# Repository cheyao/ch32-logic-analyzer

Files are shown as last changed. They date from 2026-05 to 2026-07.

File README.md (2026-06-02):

# 200Msps 16ch logic analyzer + 20Msps oscilloscope

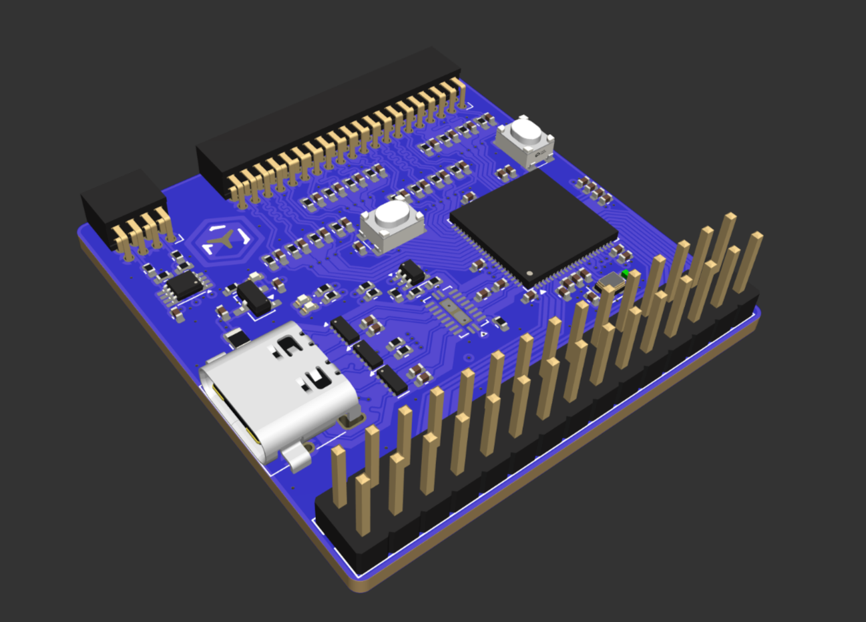
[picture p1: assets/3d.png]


This is a cheap 200Msps logic analyzer with a 20Msps analog component. It uses USB 3.2 to send data to the computer, and can also act as a ch32h417 development board.

It is usable with pulseview delivering a beautiful interface and allowing you to view all kinds of diffrent protocols. And with voltage changing, it supports 1.2V, 3.3V and 5V opration modes.

The analog channels support 20Msps at 10bit accuracy, or 5MHz at 12bit accuracy. Input range is from 0V to 5V, and it supports external triggering too!

The bottom row of header breaks out GPIO pins of various protocols, allowing the board to also become a devboard that can be programed via USB.

---

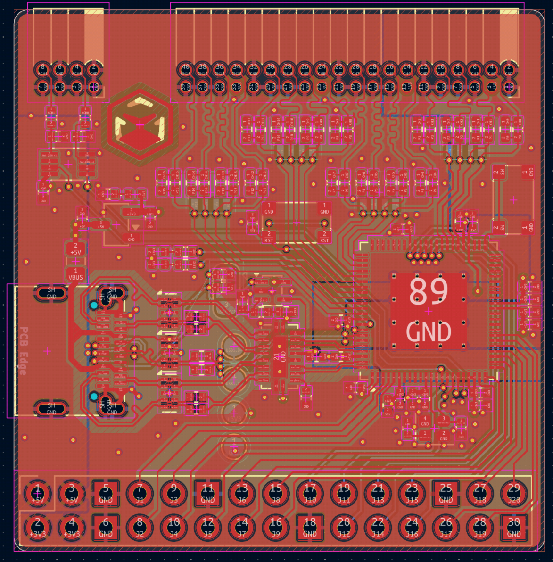
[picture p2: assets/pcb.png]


The PCB is a 4-layered board in order to preserve signal intergity on the USB 3.2 data lines. With high-quality TI active components to preserve signal quality.

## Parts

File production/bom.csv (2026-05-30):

Designator | Footprint | Quantity | Value | LCSC Part #
C1, C2 | 0402 | 2 | 33pF | C5137486
C10, C11, C12, C13, C14, C15, C16, C17, C18, C19, C20, C5, C6, C7, C8, C9 | 0402 | 16 | 15pF | C1548
C21, C22, C23, C24, C25, C26, C27, C30, C31, C32, C34, C35, C358, C359, C36, C360, C361, C38, C4 | 0402 | 19 | 100nF | C110251
C28, C29, C3, C33, C37, C39, C40 | 0402 | 7 | 4.7uF | C7472956
D1, D2, D3 | 0402 | 3 | LED | C20613596
F2 | 0805 | 1 | 1A@12V | C46640991
J1 | USB_C_Receptacle_SHOU-HAN_24P-QT | 1 | USB_C_Receptacle | C2681555
J2 | PinSocket_2x20_P1.27mm_Horizontal | 1 | Conn_02x20 | C2881906
J3 | PinSocket_2x04_P1.27mm_Horizontal | 1 | Conn_02x04 | C2881890
J4 | PinSocket_2x15_P2.54mm_Vertical | 1 | Conn_02x15 | C56496
R1, R10, R11, R12, R13, R14, R15, R16, R2, R23, R24, R25, R3, R4, R5, R6, R7, R8, R9 | 0402 | 19 | 1k | C2906864
R17, R20 | 0402 | 2 | 220R | C25091
R18, R19 | 0402 | 2 | 100R | C2906860
R21, R22 | 0402 | 2 | 5.1k | C2906874
R97, R98 | 0402 | 2 | 2.2R | C53454336
RN1, RN2, RN3, RN4 | R_Array_Convex_4x0603 | 4 | 100k | C110374
SW1, SW2 | SW_Push_SPST_TSA016 | 2 | SW_Push | C2888427
U1 | QFN-88-1EP_10x10mm_P0.4mm_EP5.7x5.7mm_ThermalVias | 1 | CH32H417MxUx
U16, U22, U23 | USON-10_2.5x1.0mm_P0.5mm | 3 | TPD4EUSB30 | C558427
U2 | VSSOP-8_2.3x2mm_P0.5mm | 1 | Opamp_Dual | C2058180
U3 | QFN-16-1EP_3x3mm_P0.5mm_EP1.75x1.75mm_ThermalVias | 1 | CH9441P | C54300797
U4 | SOT-23-3 | 1 | XC6206PxxxMR | C347376
Y1 | Crystal_SMD_2016-4Pin_2.0x1.6mm | 1 | 25MHz 20pF | C252274

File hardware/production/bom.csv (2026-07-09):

Designator | Footprint | Quantity | Value | LCSC Part #
C1, C2 | 0402 | 2 | 33pF | C5137486
C10, C11, C12, C13, C14, C15, C16, C17, C18, C19, C20, C5, C6, C7, C8, C9 | 0402 | 16 | 15pF | C1548
C21, C23, C24, C25, C26, C27, C30, C31, C32, C34, C35, C358, C359, C36, C360, C361, C38, C4 | 0402 | 18 | 100nF | C60474
C28, C29, C33, C37, C39, C40, C41 | 0402 | 7 | 4.7uF | C380302
D1, D2, D3 | 0402 | 3 | LED | C51933306
F2 | 0805 | 1 | 1A@12V | C46640991
J1 | USB_C_Receptacle_SHOU-HAN_24P-QT | 1 | USB_C_Receptacle | C2681555
J2 | PinHeader_2x20_P1.27mm_Horizontal | 1 | Conn_02x20 | C2881906
J3 | PinHeader_2x04_P1.27mm_Horizontal | 1 | Conn_02x04 | C2881890
J4, J5 | PinHeader_2x15_P2.54mm_Vertical | 2 | Conn_02x15 | C56496
R1, R10, R11, R12, R13, R14, R15, R16, R2, R23, R24, R25, R29, R3, R4, R5, R6, R7, R8, R9 | 0402 | 20 | 1k | C106235
R18, R19, R20, R30 | 0402 | 4 | 100R | C106232
R21, R22, R26, R27, R28 | 0402 | 5 | 5.1k | C105872
R97, R98 | 0402 | 2 | 2.2R | C54920775
RN1, RN2, RN3, RN4 | R_Array_Convex_4x0603 | 4 | 100k | C110374
SW1, SW2 | SW_Push_SPST_TSA016 | 2 | SW_Push | C2888427
U1 | QFN-88-1EP_10x10mm_P0.4mm_EP5.7x5.7mm_ThermalVias | 1 | CH32H417MxUx | C54973456
U16, U22, U23 | USON-10_2.5x1.0mm_P0.5mm | 3 | TPD4EUSB30 | C558427
U2 | SOT-89-3 | 1 | AMS1117-3.3 | C347256
U3 | SOT-353_SC-70-5 | 1 | LMV321 | C3029047
U5 | DHVQFN-20-1EP_2.5x4.5mm_P0.5mm_EP1x3mm | 1 | TMUXHS4212 | C2869871
Y1 | Crystal_SMD_2016-4Pin_2.0x1.6mm | 1 | 25MHz 20pF | C37635326

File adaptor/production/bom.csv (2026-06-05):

Designator | Footprint | Quantity | Value | LCSC Part #
J1 | Edge_1.27mm_02x04 | 1 | Conn_02x04_Odd_Even
J2 | Edge_1.27mm_02x20 | 1 | Conn_02x20 | C2881906
J3 | Edge_2.54mm_02x20 | 1 | Conn_02x20 | C2881906
J4 | Edge_2.54mm_02x04 | 1 | Conn_02x04_Odd_Even

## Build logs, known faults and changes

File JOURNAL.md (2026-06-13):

Day 1 - 1.5h

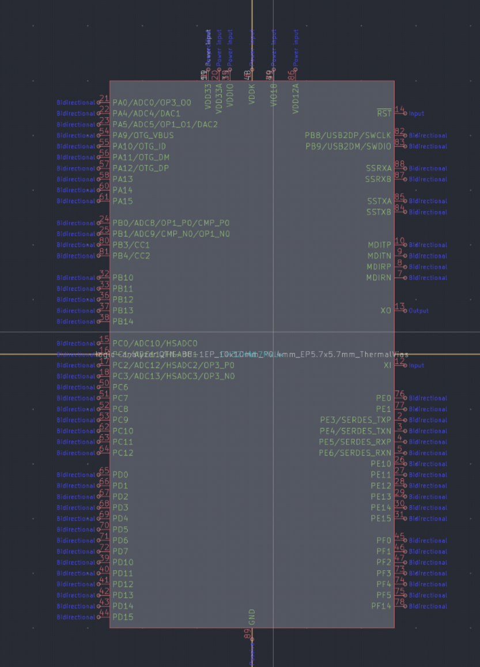
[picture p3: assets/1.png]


Drew the CH32H417 symbol and its QFN-88 footprint

---

Day 2 - 4.3h

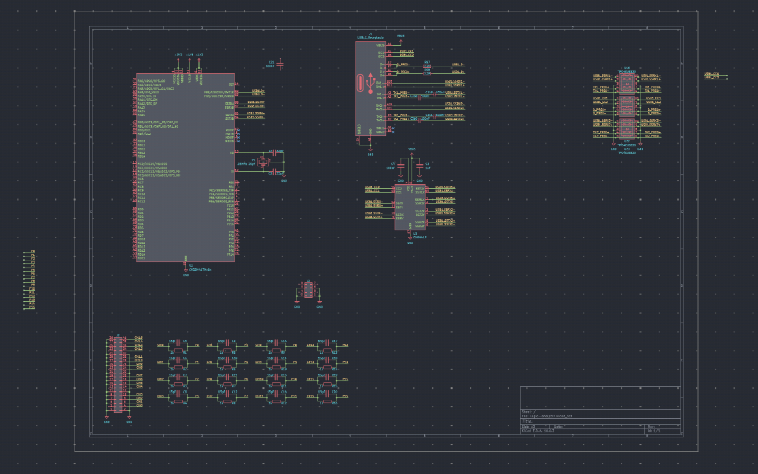
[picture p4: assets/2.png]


Improved the schmatic, picked some chips

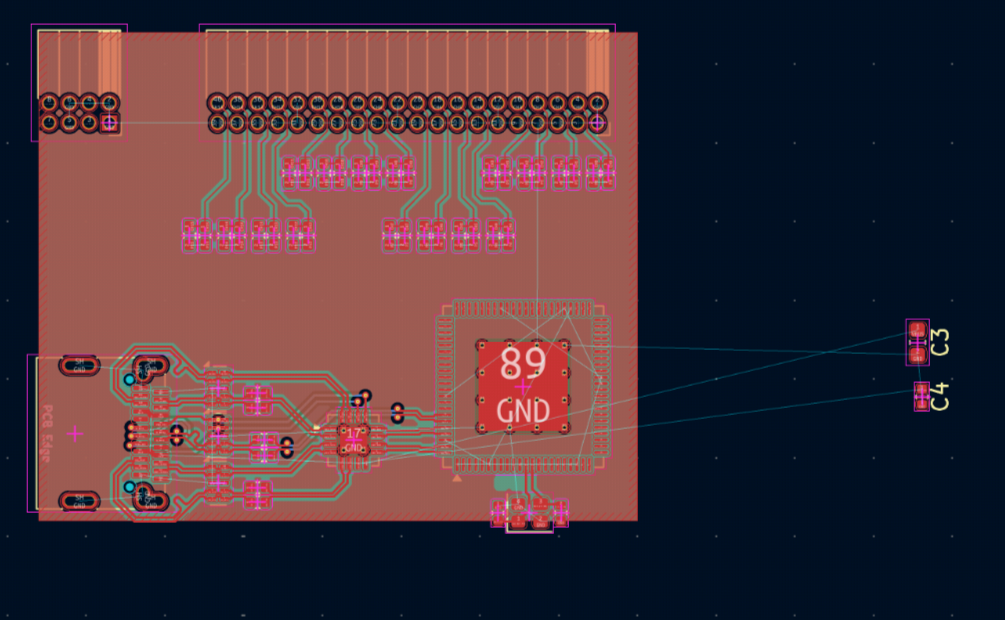
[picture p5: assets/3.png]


And started laying the board out

---

Day 3 - 6.8h

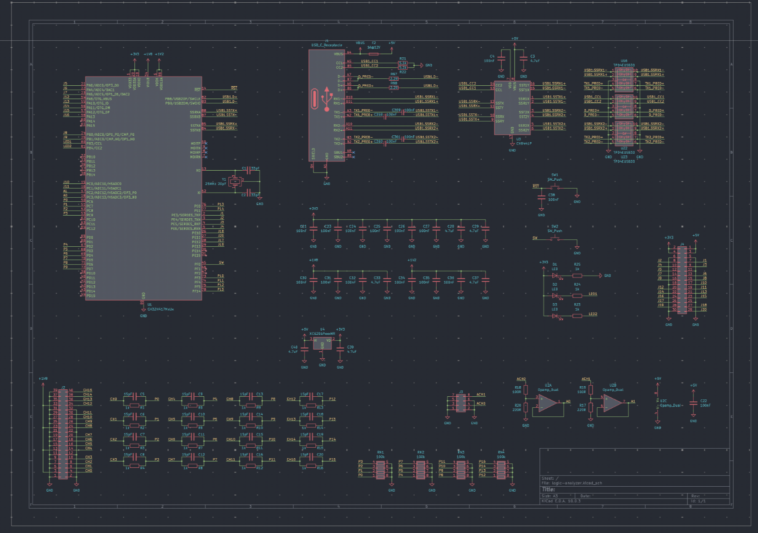
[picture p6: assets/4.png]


Finished the schematic! Added a ADC opamp voltage conv, power circuits and decoupling n more

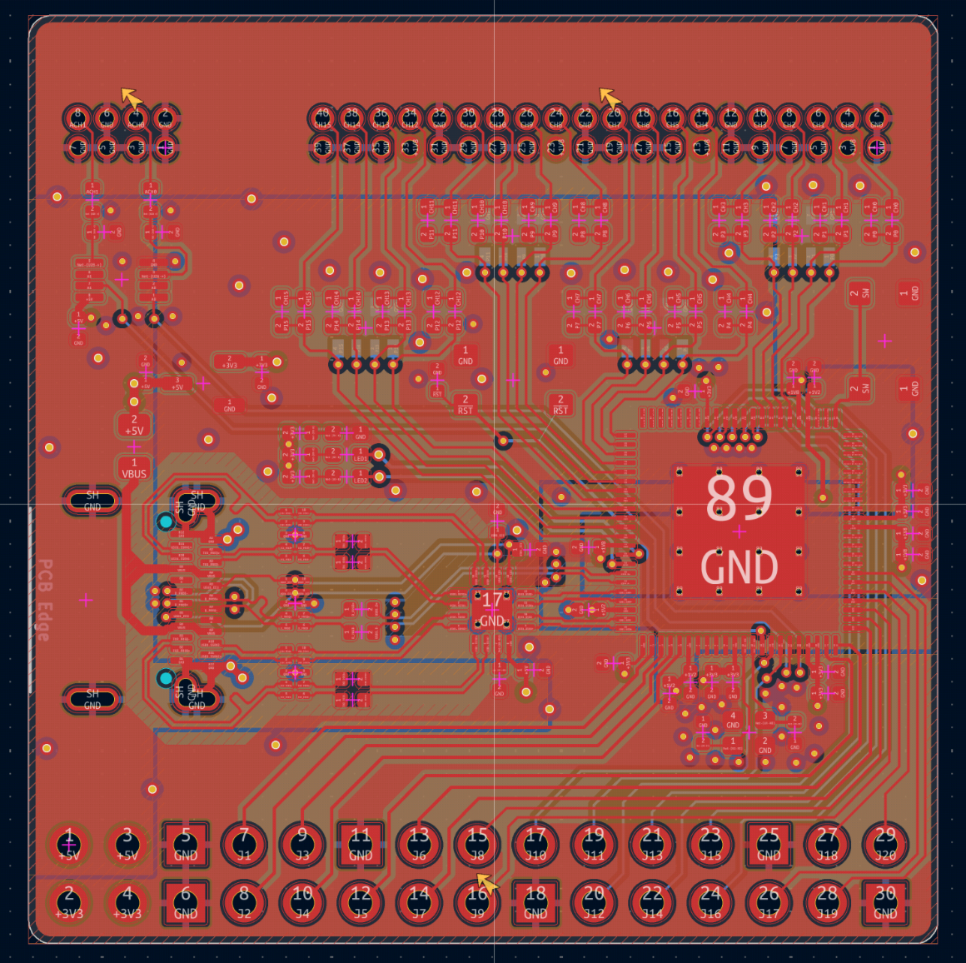
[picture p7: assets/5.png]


Then routed out the PCB, took into acount the super-high-speed routes etc

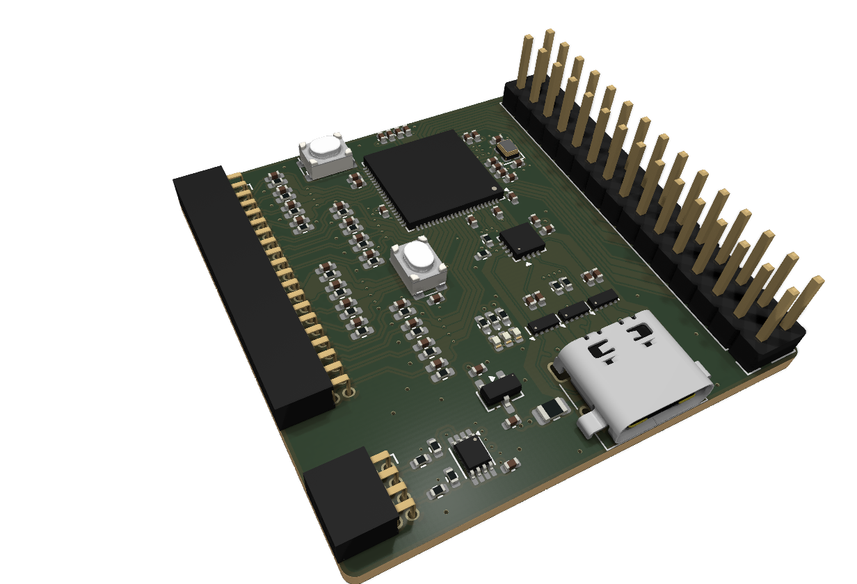
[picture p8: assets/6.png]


Also spent a bit of time fixing all the 3d models

---

Day 4 - 4.3h

Changed the unavailable parts to something more common, and used a opamp to trigger the switch instead of mcu firmware. Studied this circuit a tiny bit.

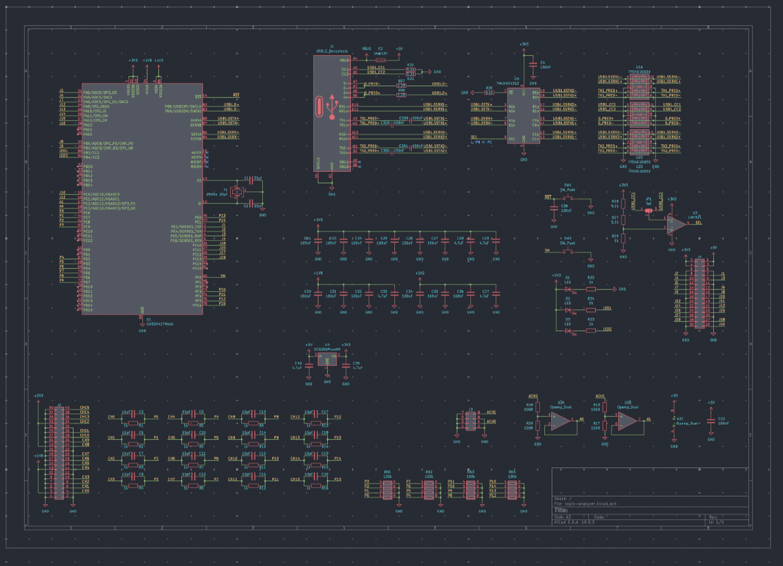
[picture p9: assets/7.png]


Also re-did the high speed routing:

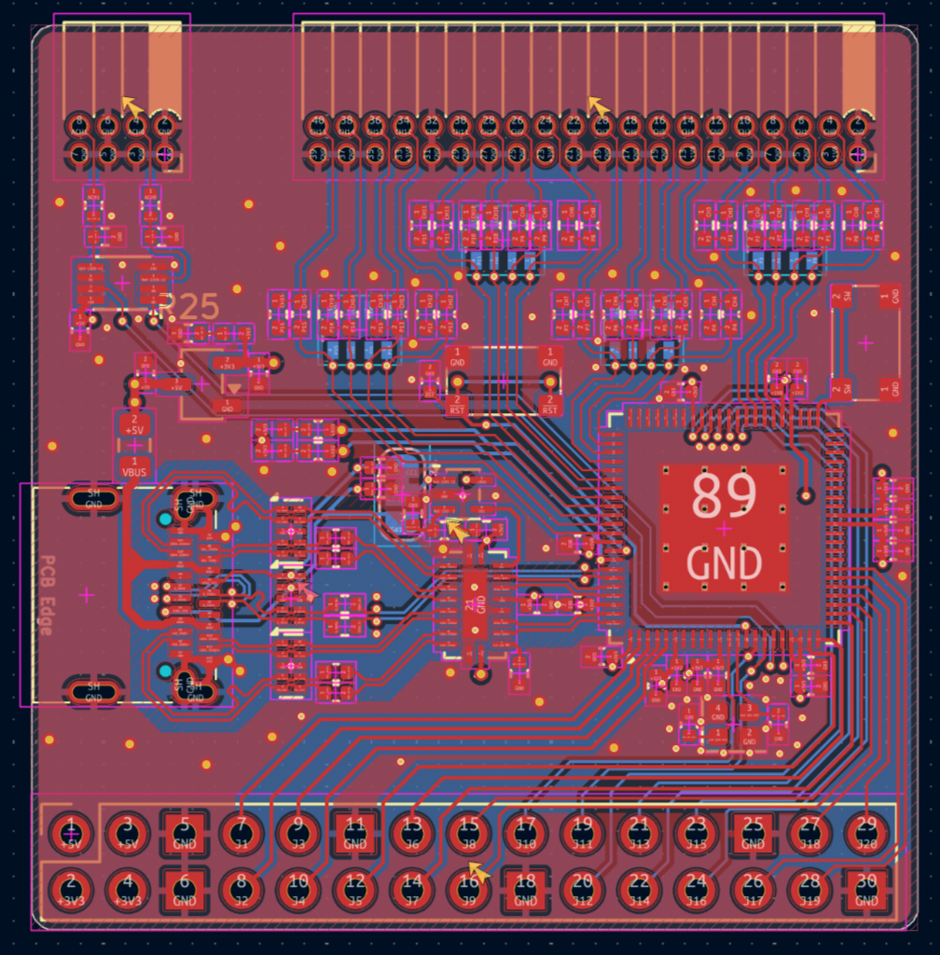
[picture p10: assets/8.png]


---

Day 5 - 1.2h

Shipped the project!

Polished everything and wrote the readme, you can see the difference between the pic above and the pic in the readme



:D

---

Day 6 - 4.6h

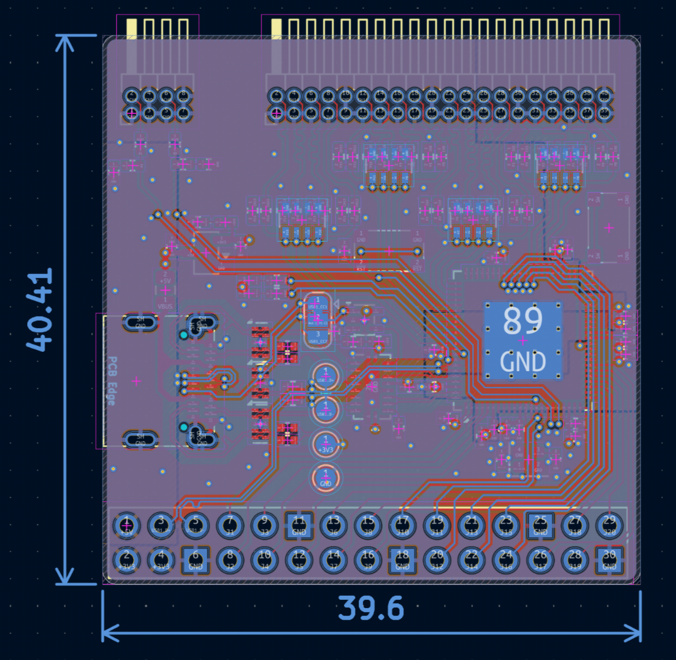
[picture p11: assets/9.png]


This time I thought about how to program the board lmao, broke out the swio pads.

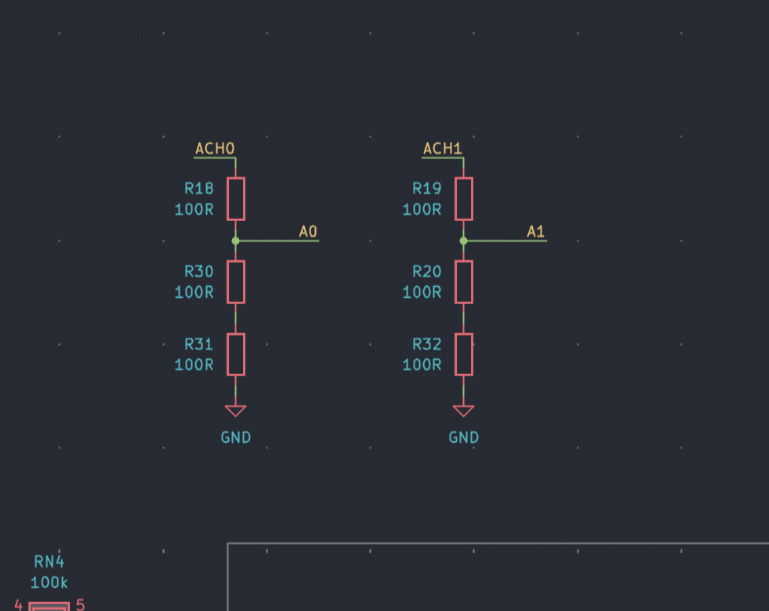
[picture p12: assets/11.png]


Also changed the OPA to resistor devider to bom opt, and changed a lot of component numbers.

Fixed the power planes, or more like optimized them

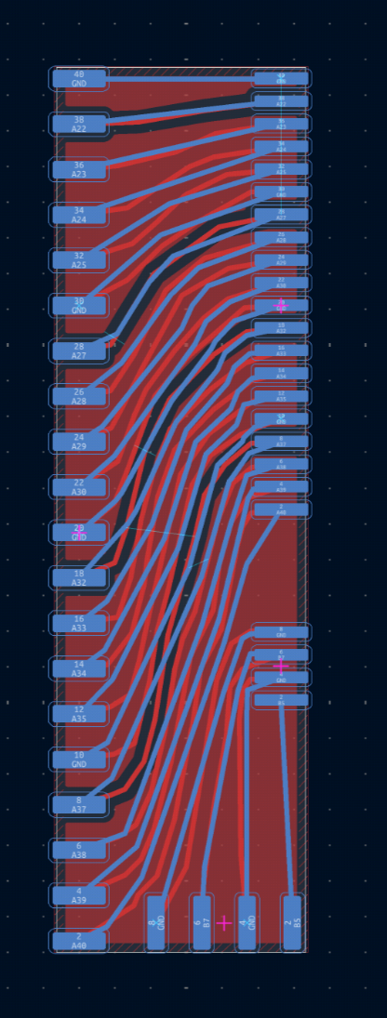
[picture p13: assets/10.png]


At the same time, I made a small breakout board to get bigger headers.

Gotten a few quotes too! Been a pita to add everything

---

Day 7 - 4.9h

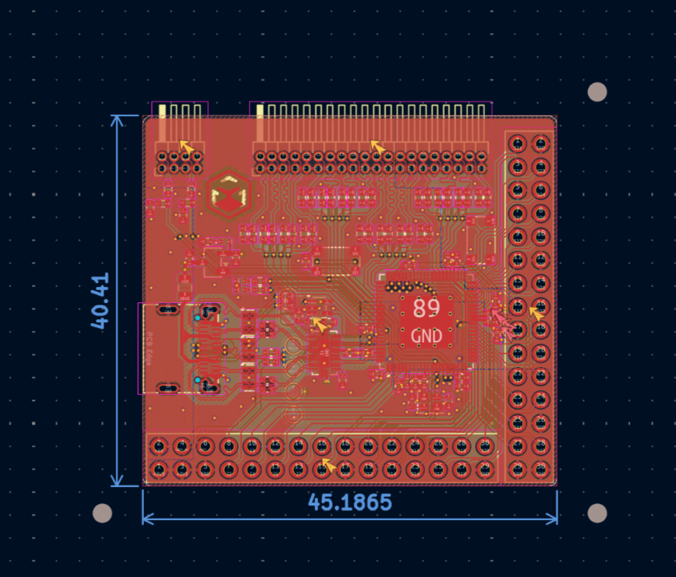
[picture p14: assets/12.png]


Welp, guess what. I broke out more pins and added flucidals to the board

Also improved routing on the back!

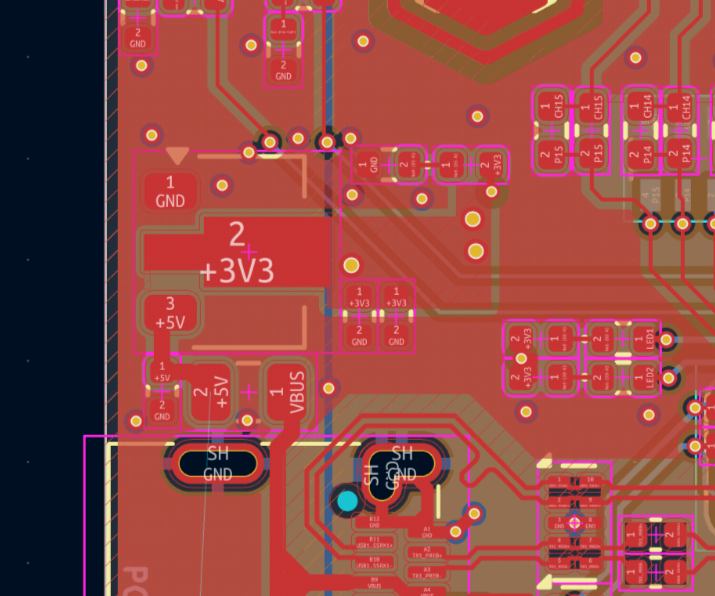
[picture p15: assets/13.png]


At the same time, I fixed the voltage regulator problem. Now 3v3 rail will be able to supply 1A of current.

---

Day 8, 9, 10 etc. - 3h

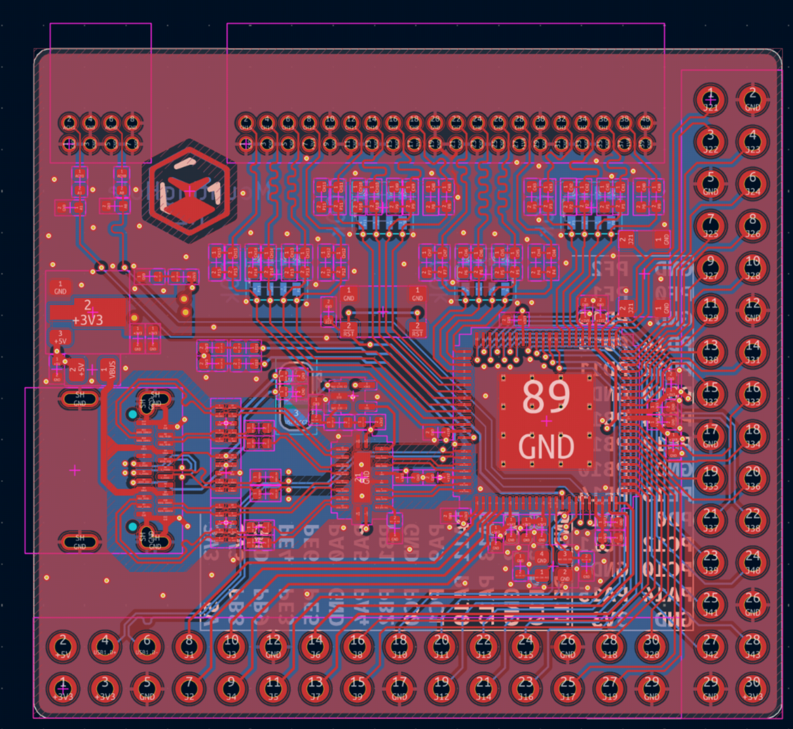
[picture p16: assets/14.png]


Improved USB SS signaling - got inter-pair skew low and also maintained more grounding

Also did a lot of misc changes, you can see the difference in the picture

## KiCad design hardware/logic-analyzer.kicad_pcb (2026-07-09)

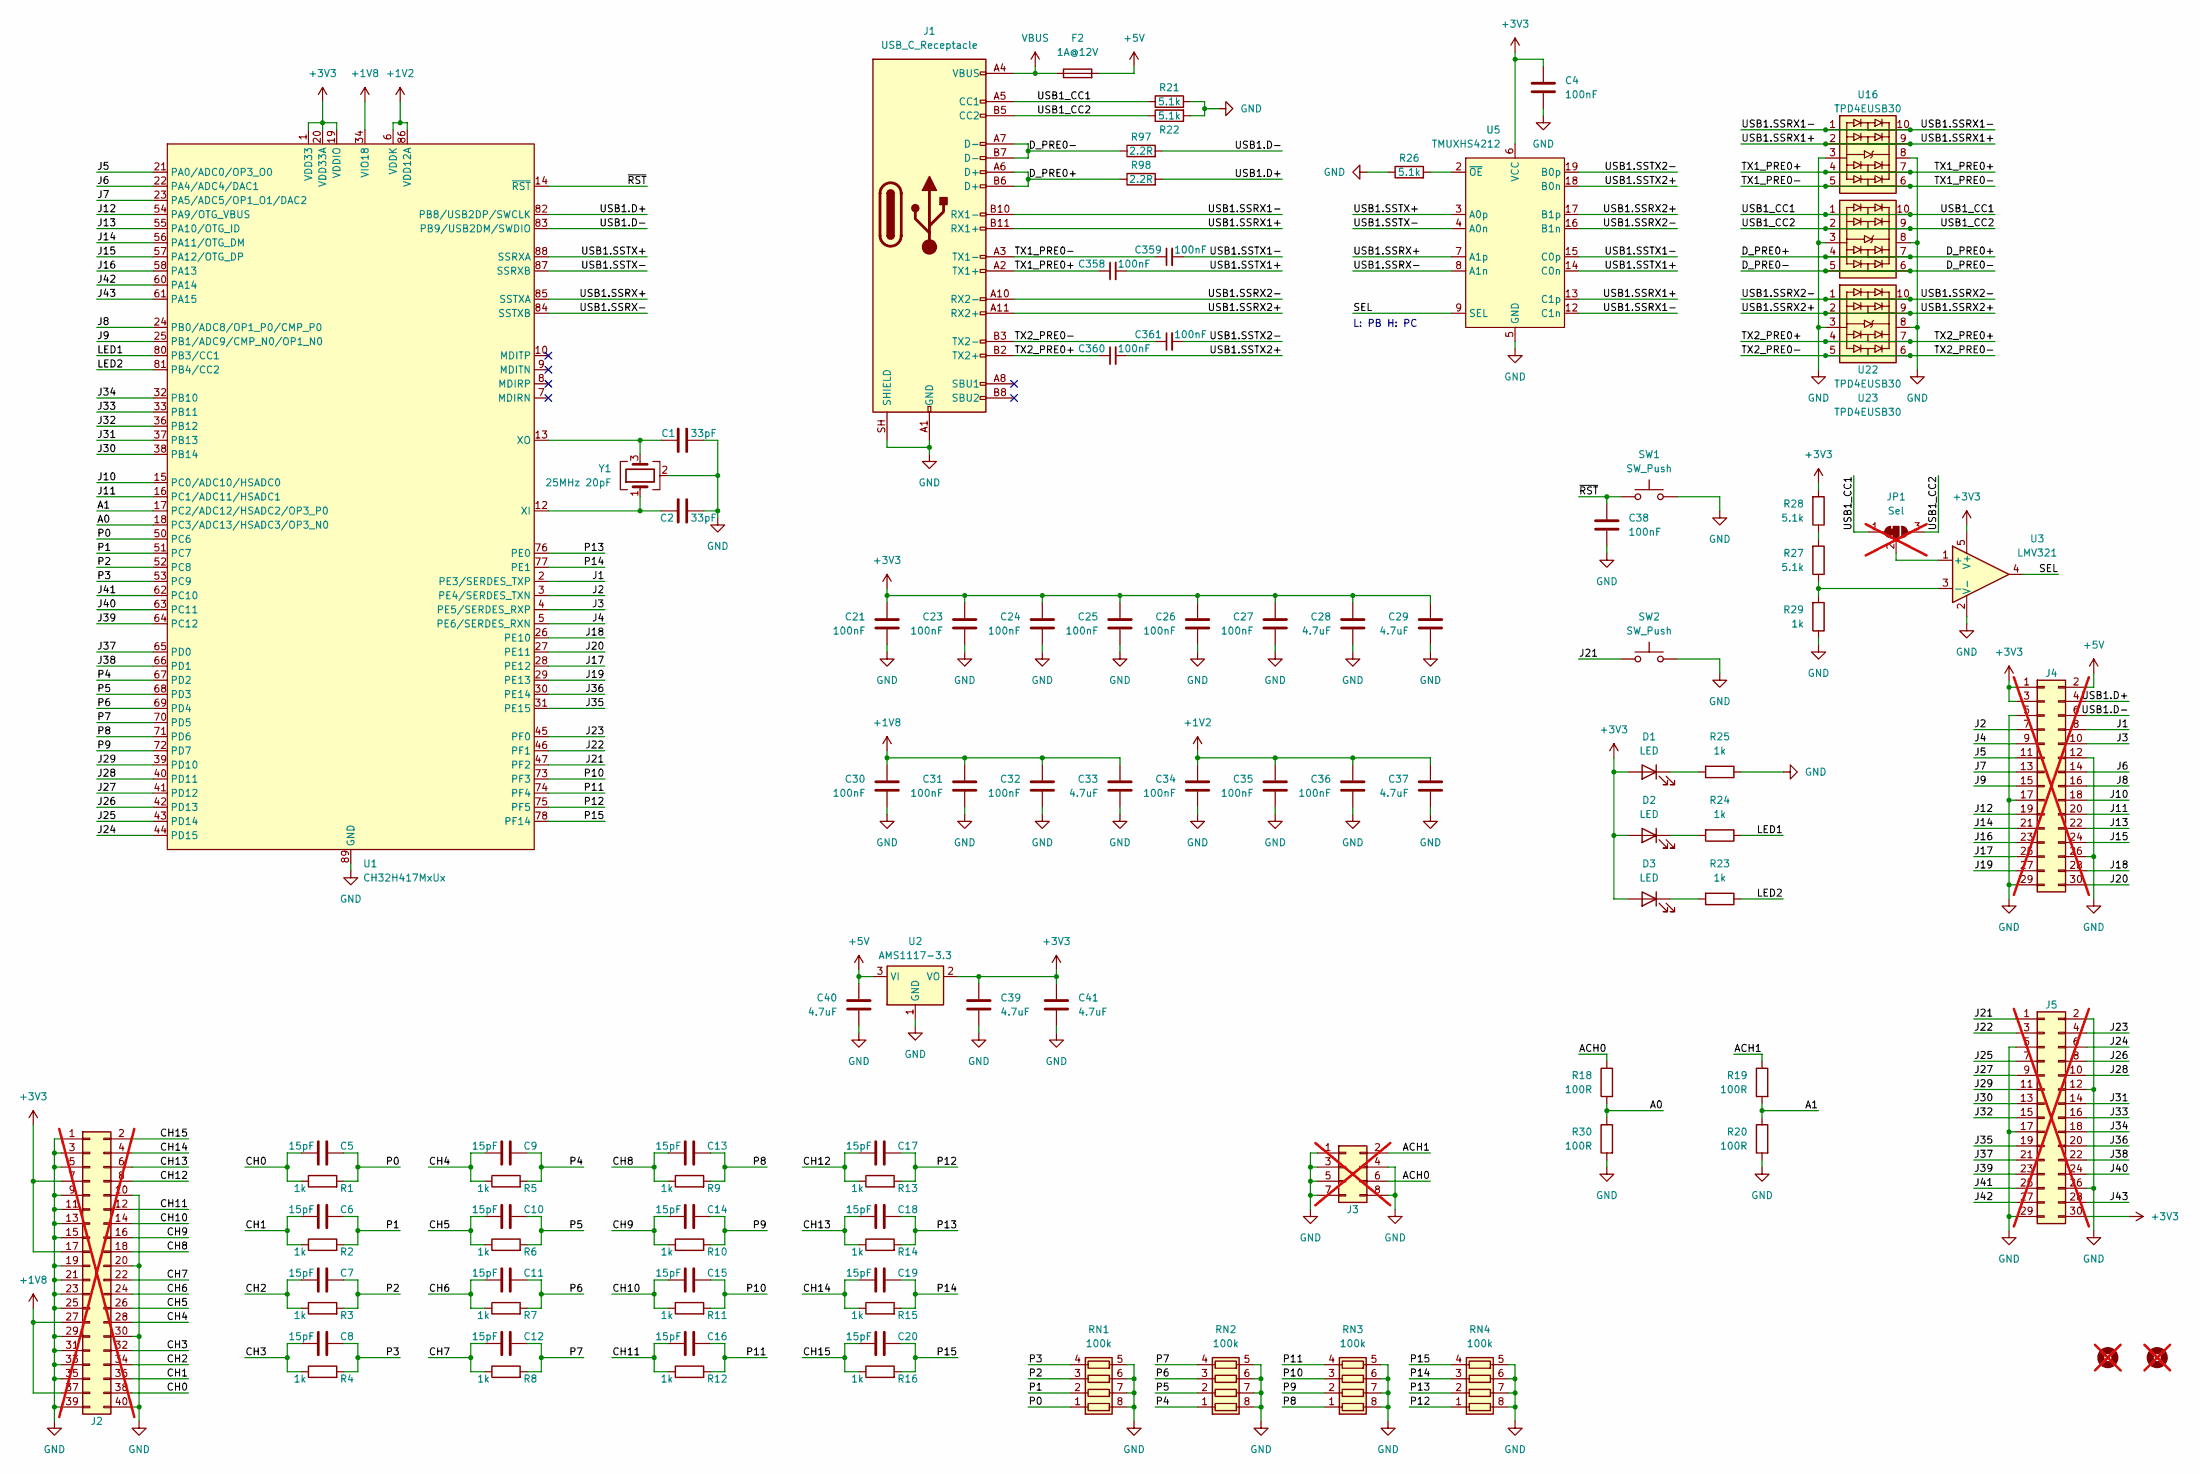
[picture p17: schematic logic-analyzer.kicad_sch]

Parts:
C1, C2: 33pF; C_0402_1005Metric; MPN GCM1555C1H330JA16J; LCSC Part # C5137486
C4, C21, C23, C24, C25, C26, C27, C30, C31, C32, C34, C35, C36, C38, C358, C359, C360, C361: 100nF; C_0402_1005Metric; MPN CC0402KRX7R7BB104; LCSC Part # C60474
C5, C6, C7, C8, C9, C10, C11, C12, C13, C14, C15, C16, C17, C18, C19, C20: 15pF; C_0402_1005Metric_Pad0.74x0.62mm_HandSolder; MPN VJ0402A150JXAAC; LCSC Part # C1548
C28, C29, C33, C37, C39, C40, C41: 4.7uF; C_0402_1005Metric; MPN GRM155R60G475ME87D; LCSC Part # C380302
D1, D2, D3: LED; LED_0402_1005Metric; LCSC Part # C51933306
F2: 1A@12V; Fuse_0805_2012Metric; LCSC Part # C46640991
H1, H2: MountingHole; Icy Electronics Logo; not fitted
J1: USB_C_Receptacle; USB_C_Receptacle_SHOU-HAN_24P-QT; LCSC Part # C2681555
J2: Conn_02x20; PinHeader_2x20_P1.27mm_Horizontal; LCSC Part # C2881906; not fitted
J3: Conn_02x04; PinHeader_2x04_P1.27mm_Horizontal; LCSC Part # C2881890; not fitted
J4, J5: Conn_02x15; PinHeader_2x15_P2.54mm_Vertical; LCSC Part # C56496; not fitted
JP1: Sel; SolderJumper-3_P1.3mm_Bridged12_RoundedPad1.0x1.5mm; not fitted
R1, R2, R3, R4, R5, R6, R7, R8, R9, R10, R11, R12, R13, R14, R15, R16: 1k; R_0402_1005Metric_Pad0.72x0.64mm_HandSolder; MPN RC0402FR-071KL; LCSC Part # C11702
R18, R19, R20, R30: 100R; R_0402_1005Metric; MPN MCS04020C1000FE000; LCSC Part # C705627
R21, R22, R26, R27, R28: 5.1k; R_0402_1005Metric; MPN AC0402FR-075K1L; LCSC Part # C852856
R23, R24, R25, R29: 1k; R_0402_1005Metric; MPN RC0402FR-071KL; LCSC Part # C852624
R97, R98: 2.2R; R_0402_1005Metric; MPN RC0402FR-072R2L; LCSC Part # C100632
RN1, RN2, RN3, RN4: 100k; R_Array_Convex_4x0603; MPN EXB-V8V104JV; LCSC Part # C110374
SW1, SW2: SW_Push; SW_Push_SPST_TSA016; LCSC Part # C2888428
U1: CH32H417MxUx; QFN-88-1EP_10x10mm_P0.4mm_EP5.7x5.7mm_ThermalVias; MPN CH32H417MEU6; LCSC Part # C54973456
U2: AMS1117-3.3; SOT-89-3; LCSC Part # C347256
U3: LMV321; SOT-353_SC-70-5; MPN LMV321IDCKT; LCSC Part # C3029047
U5: TMUXHS4212; DHVQFN-20-1EP_2.5x4.5mm_P0.5mm_EP1x3mm; MPN TMUXHS4212RKSR; LCSC Part # C2869871
U16, U22, U23: TPD4EUSB30; USON-10_2.5x1.0mm_P0.5mm; MPN TPD4EUSB30DQAR; LCSC Part # C558427
Y1: 25MHz 20pF; Crystal_SMD_2016-4Pin_2.0x1.6mm; MPN XT1220HJRGX25M00E; LCSC Part # C37635326

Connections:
+1V2: C34.1, C35.1, C36.1, C37.1, U1.6 (VDDK), U1.48 (VDDK), U1.86 (VDD12A)
+1V8: C30.1, C31.1, C32.1, C33.1, J2.27, J2.37, U1.34 (VIO18), U1.49 (VIO18), U1.79 (VIO18)
+3V3: C4.1, C21.1, C23.1, C24.1, C25.1, C26.1, C27.1, C28.1, C29.1, C39.1, C41.1, D1.2 (A), D2.2 (A), D3.2 (A), J2.7, J2.17, J4.1, J4.3, J5.30, R28.2, U1.1 (VDD33), U1.11 (VDD33), U1.19 (VDDIO), U1.20 (VDD33A), U1.35 (VDDIO), U1.59 (VDD33), U2.2 (VO), U3.5 (V+), U5.1 (RSVD1), U5.6 (VCC), U5.10 (RSVD2)
+5V: C40.1, F2.2, J4.2, U2.3 (VI)
/A0: R18.2, R30.1, U1.18 (PC3/ADC13/HSADC3/OP3_N0)
/A1: R19.2, R20.1, U1.17 (PC2/ADC12/HSADC2/OP3_P0)
/ACH0: J3.6, R18.1
/ACH1: J3.2, R19.1
/CH0: C5.1, J2.38, R1.1
/CH1: C6.1, J2.36, R2.1
/CH2: C7.1, J2.34, R3.1
/CH3: C8.1, J2.32, R4.1
/CH4: C9.1, J2.28, R5.1
/CH5: C10.1, J2.26, R6.1
/CH6: C11.1, J2.24, R7.1
/CH7: C12.1, J2.22, R8.1
/CH8: C13.1, J2.18, R9.1
/CH9: C14.1, J2.16, R10.1
/CH10: C15.1, J2.14, R11.1
/CH11: C16.1, J2.12, R12.1
/CH12: C17.1, J2.8, R13.1
/CH13: C18.1, J2.6, R14.1
/CH14: C19.1, J2.4, R15.1
/CH15: C20.1, J2.2, R16.1
/D_PRE0+: J1.A6 (D+), J1.B6 (D+), R98.1, U22.4, U22.7
/D_PRE0-: J1.A7 (D-), J1.B7 (D-), R97.1, U22.5, U22.6
/J1: J4.8, U1.2 (PE3/SERDES_TXP)
/J2: J4.7, U1.3 (PE4/SERDES_TXN)
/J3: J4.10, U1.4 (PE5/SERDES_RXP)
/J4: J4.9, U1.5 (PE6/SERDES_RXN)
/J5: J4.11, U1.21 (PA0/ADC0/OP3_O0)
/J6: J4.14, U1.22 (PA4/ADC4/DAC1)
/J7: J4.13, U1.23 (PA5/ADC5/OP1_O1/DAC2)
/J8: J4.16, U1.24 (PB0/ADC8/OP1_P0/CMP_P0)
/J9: J4.15, U1.25 (PB1/ADC9/CMP_N0/OP1_N0)
/J10: J4.18, U1.15 (PC0/ADC10/HSADC0)
/J11: J4.20, U1.16 (PC1/ADC11/HSADC1)
/J12: J4.19, U1.54 (PA9/OTG_VBUS)
/J13: J4.22, U1.55 (PA10/OTG_ID)
/J14: J4.21, U1.56 (PA11/OTG_DM)
/J15: J4.24, U1.57 (PA12/OTG_DP)
/J16: J4.23, U1.58 (PA13)
/J17: J4.25, U1.28 (PE12)
/J18: J4.28, U1.26 (PE10)
/J19: J4.27, U1.29 (PE13)
/J20: J4.30, U1.27 (PE11)
/J21: J5.1, SW2.2, U1.47 (PF2)
/J22: J5.3, U1.46 (PF1)
/J23: J5.4, U1.45 (PF0)
/J24: J5.6, U1.44 (PD15)
/J25: J5.7, U1.43 (PD14)
/J26: J5.8, U1.42 (PD13)
/J27: J5.9, U1.41 (PD12)
/J28: J5.10, U1.40 (PD11)
/J29: J5.11, U1.39 (PD10)
/J30: J5.13, U1.38 (PB14)
/J31: J5.14, U1.37 (PB13)
/J32: J5.15, U1.36 (PB12)
/J33: J5.16, U1.33 (PB11)
/J34: J5.18, U1.32 (PB10)
/J35: J5.19, U1.31 (PE15)
/J36: J5.20, U1.30 (PE14)
/J37: J5.21, U1.65 (PD0)
/J38: J5.22, U1.66 (PD1)
/J39: J5.23, U1.64 (PC12)
/J40: J5.24, U1.63 (PC11)
/J41: J5.25, U1.62 (PC10)
/J42: J5.27, U1.60 (PA14)
/J43: J5.28, U1.61 (PA15)
/LED1: R24.1, U1.80 (PB3/CC1)
/LED2: R23.1, U1.81 (PB4/CC2)
/P0: C5.2, R1.2, RN1.1 (R1.1), U1.50 (PC6)
/P1: C6.2, R2.2, RN1.2 (R2.1), U1.51 (PC7)
/P2: C7.2, R3.2, RN1.3 (R3.1), U1.52 (PC8)
/P3: C8.2, R4.2, RN1.4 (R4.1), U1.53 (PC9)
/P4: C9.2, R5.2, RN2.1 (R1.1), U1.67 (PD2)
/P5: C10.2, R6.2, RN2.2 (R2.1), U1.68 (PD3)
/P6: C11.2, R7.2, RN2.3 (R3.1), U1.69 (PD4)
/P7: C12.2, R8.2, RN2.4 (R4.1), U1.70 (PD5)
/P8: C13.2, R9.2, RN3.1 (R1.1), U1.71 (PD6)
/P9: C14.2, R10.2, RN3.2 (R2.1), U1.72 (PD7)
/P10: C15.2, R11.2, RN3.3 (R3.1), U1.73 (PF3)
/P11: C16.2, R12.2, RN3.4 (R4.1), U1.74 (PF4)
/P12: C17.2, R13.2, RN4.1 (R1.1), U1.75 (PF5)
/P13: C18.2, R14.2, RN4.2 (R2.1), U1.76 (PE0)
/P14: C19.2, R15.2, RN4.3 (R3.1), U1.77 (PE1)
/P15: C20.2, R16.2, RN4.4 (R4.1), U1.78 (PF14)
/SEL: U3.4, U5.9 (SEL)
/TX1_PRE0+: C358.1, J1.A2 (TX1+), U16.4, U16.7
/TX1_PRE0-: C359.1, J1.A3 (TX1-), U16.5, U16.6
/TX2_PRE0+: C360.1, J1.B2 (TX2+), U23.4, U23.7
/TX2_PRE0-: C361.1, J1.B3 (TX2-), U23.5, U23.6
/USB1.D+: J4.4, R98.2, U1.82 (PB8/USB2DP/SWCLK)
/USB1.D-: J4.6, R97.2, U1.83 (PB9/USB2DM/SWDIO)
/USB1.SSRX1+: J1.B11 (RX1+), U5.13 (C1p), U16.2, U16.9
/USB1.SSRX1-: J1.B10 (RX1-), U5.12 (C1n), U16.1, U16.10
/USB1.SSRX2+: J1.A11 (RX2+), U5.17 (B1p), U23.2, U23.9
/USB1.SSRX2-: J1.A10 (RX2-), U5.16 (B1n), U23.1, U23.10
/USB1.SSRX+: U1.85 (SSTXA), U5.7 (A1p)
/USB1.SSRX-: U1.84 (SSTXB), U5.8 (A1n)
/USB1.SSTX1+: C358.2, U5.14 (C0n)
/USB1.SSTX1-: C359.2, U5.15 (C0p)
/USB1.SSTX2+: C360.2, U5.18 (B0n)
/USB1.SSTX2-: C361.2, U5.19 (B0p)
/USB1.SSTX+: U1.88 (SSRXA), U5.3 (A0p)
/USB1.SSTX-: U1.87 (SSRXB), U5.4 (A0n)
/USB1_CC1: J1.A5 (CC1), JP1.1 (A), R21.1, U22.1, U22.10
/USB1_CC2: J1.B5 (CC2), JP1.3 (B), R22.1, U22.2, U22.9
/~RST: C38.1, SW1.2, U1.14 (~RST)
GND: C1.1, C2.1, C4.2, C21.2, C23.2, C24.2, C25.2, C26.2, C27.2, C28.2, C29.2, C30.2, C31.2, C32.2, C33.2, C34.2, C35.2, C36.2, C37.2, C38.2, C39.2, C40.2, C41.2, J1.A1 (GND), J1.A12 (GND), J1.B1 (GND), J1.B12 (GND), J1.SH (SHIELD), J2.1, J2.3, J2.5, J2.9, J2.10, J2.11, J2.13, J2.15, J2.19, J2.20, J2.21, J2.23, J2.25, J2.29, J2.30, J2.31, J2.33, J2.35, J2.39, J2.40, J3.1, J3.3, J3.4, J3.5, J3.7, J3.8, J4.5, J4.12, J4.17, J4.26, J4.29, J5.2, J5.5, J5.12, J5.17, J5.26, J5.29, R20.2, R21.2, R22.2, R25.1, R26.1, R29.1, R30.2, RN1.5 (R4.2), RN1.6 (R3.2), RN1.7 (R2.2), RN1.8 (R1.2), RN2.5 (R4.2), RN2.6 (R3.2), RN2.7 (R2.2), RN2.8 (R1.2), RN3.5 (R4.2), RN3.6 (R3.2), RN3.7 (R2.2), RN3.8 (R1.2), RN4.5 (R4.2), RN4.6 (R3.2), RN4.7 (R2.2), RN4.8 (R1.2), SW1.1, SW2.1, U1.89 (GND), U2.1 (GND), U3.2 (V-), U5.5 (GND), U5.11 (GND), U5.20 (GND), U5.21 (GND), U16.3, U16.8, U22.3, U22.8, U23.3, U23.8, Y1.2 (G), Y1.4 (G)
unnamed: D1.1 (K), R25.2
unnamed: D2.1 (K), R24.2
unnamed: D3.1 (K), R23.2
unnamed: JP1.2 (C), U3.1 (+)
unnamed: R27.2, R28.1
unnamed: C2.2, U1.12 (XI), Y1.1
unnamed: C1.2, U1.13 (XO), Y1.3
unnamed: R27.1, R29.2, U3.3 (-)
unnamed: R26.2, U5.2 (~OE)
VBUS: F2.1, J1.A4 (VBUS), J1.A9 (VBUS), J1.B4 (VBUS), J1.B9 (VBUS)

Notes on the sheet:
L: PB H: PC

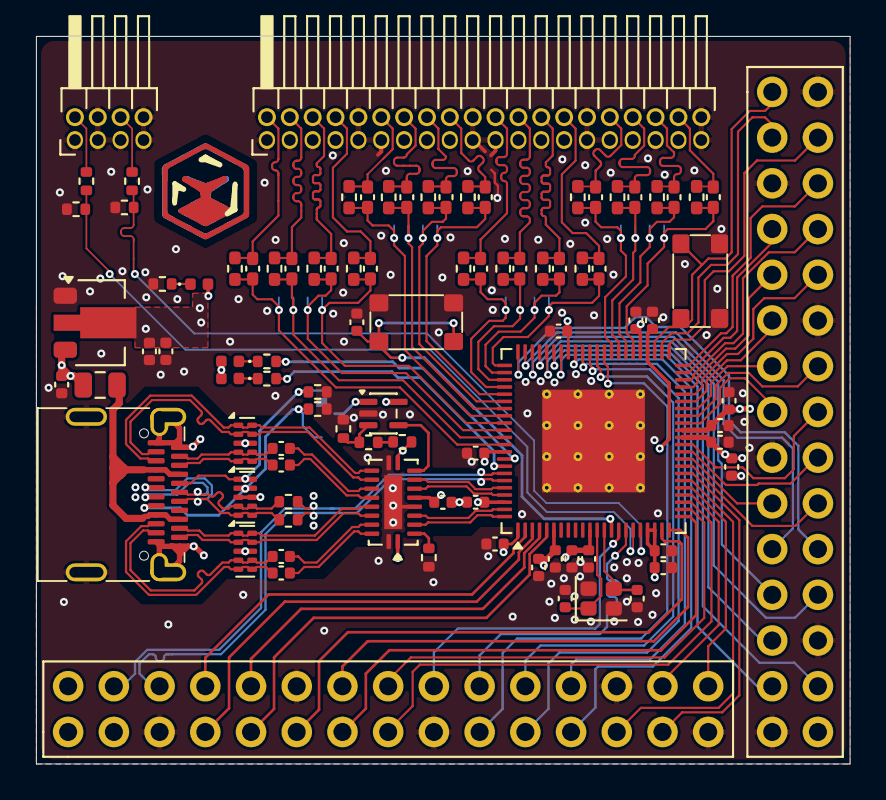
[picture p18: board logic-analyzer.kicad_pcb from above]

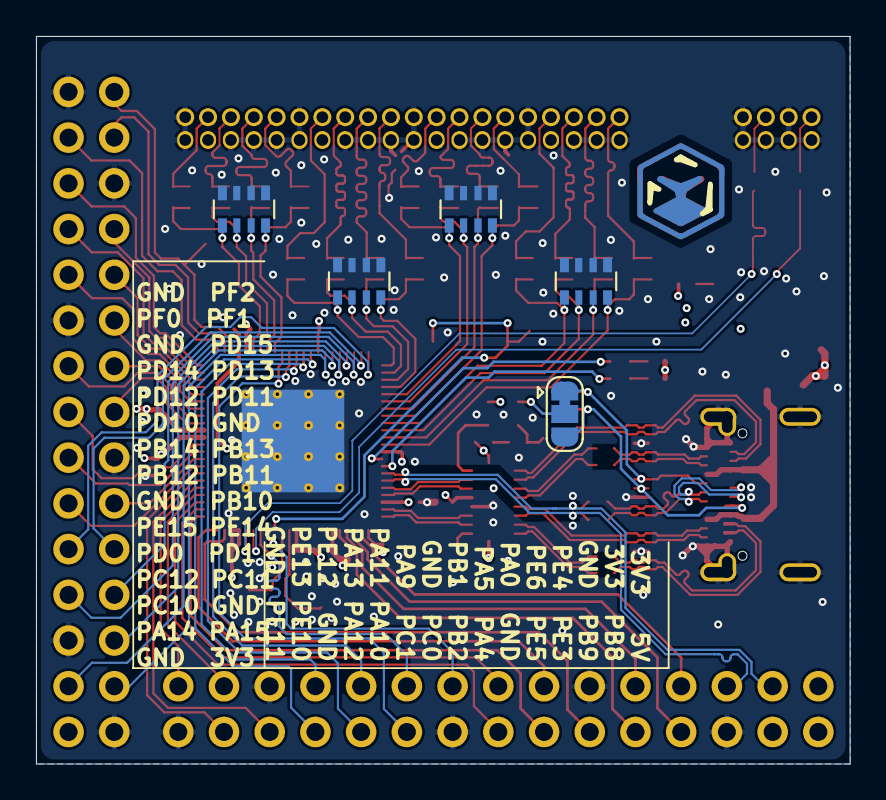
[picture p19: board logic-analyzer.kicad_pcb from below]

Board: 4 copper layers, 45.2 x 40.4 mm, 100 parts (6 on the bottom side), 120 nets.

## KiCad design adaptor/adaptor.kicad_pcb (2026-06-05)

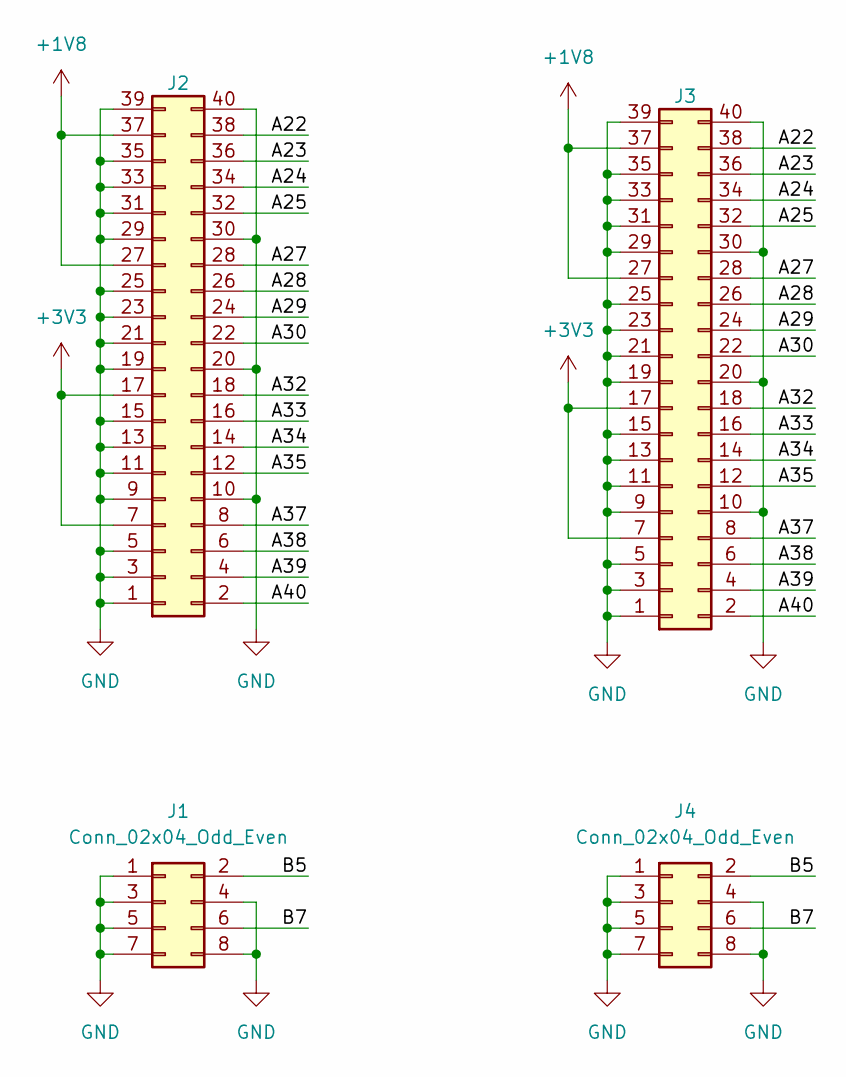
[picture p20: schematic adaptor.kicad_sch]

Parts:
J1: Conn_02x04_Odd_Even; Edge_1.27mm_02x04
J2: Conn_02x20; Edge_1.27mm_02x20; LCSC Part # C2881906
J3: Conn_02x20; Edge_2.54mm_02x20; LCSC Part # C2881906
J4: Conn_02x04_Odd_Even; Edge_2.54mm_02x04

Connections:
+1V8: J2.27, J2.37, J3.27, J3.37
+3V3: J2.7, J2.17, J3.7, J3.17
/A22: J2.38, J3.38
/A23: J2.36, J3.36
/A24: J2.34, J3.34
/A25: J2.32, J3.32
/A27: J2.28, J3.28
/A28: J2.26, J3.26
/A29: J2.24, J3.24
/A30: J2.22, J3.22
/A32: J2.18, J3.18
/A33: J2.16, J3.16
/A34: J2.14, J3.14
/A35: J2.12, J3.12
/A37: J2.8, J3.8
/A38: J2.6, J3.6
/A39: J2.4, J3.4
/A40: J2.2, J3.2
/B5: J1.2, J4.2
/B7: J1.6, J4.6
GND: J1.1, J1.3, J1.4, J1.5, J1.7, J1.8, J2.1, J2.3, J2.5, J2.9, J2.10, J2.11, J2.13, J2.15, J2.19, J2.20, J2.21, J2.23, J2.25, J2.29, J2.30, J2.31, J2.33, J2.35, J2.39, J2.40, J3.1, J3.3, J3.5, J3.9, J3.10, J3.11, J3.13, J3.15, J3.19, J3.20, J3.21, J3.23, J3.25, J3.29, J3.30, J3.31, J3.33, J3.35, J3.39, J3.40, J4.1, J4.3, J4.4, J4.5, J4.7, J4.8

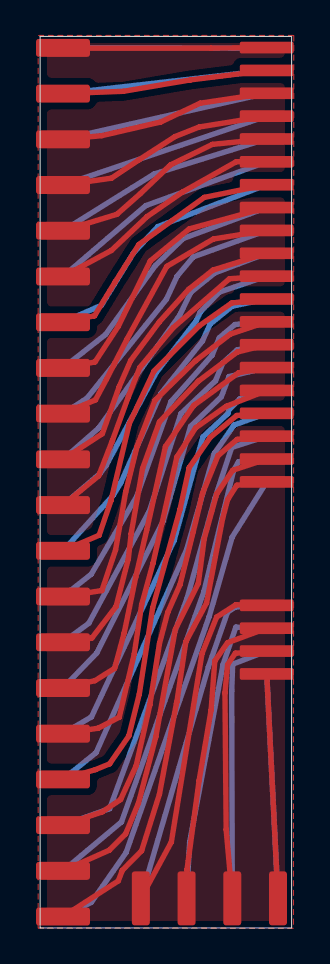
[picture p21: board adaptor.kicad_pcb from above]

Board: 2 copper layers, 14.0 x 49.5 mm, 4 parts (0 on the bottom side), 21 nets.

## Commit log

2026-05-30 CH9441P variant
    [bom.csv, designators.csv, logic-analyzer.kicad_pcb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]
2026-05-30 Change CH9441P into something available
    [logic-analyzer.kicad_pcb, logic-analyzer.kicad_sch]
2026-06-13 General improvements
    [bom.csv, designators.csv, logic-analyzer.kicad_pcb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]
